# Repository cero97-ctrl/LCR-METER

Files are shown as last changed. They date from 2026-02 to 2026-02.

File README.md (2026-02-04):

# DIY LC Meter Project

This project demonstrates how to build a DIY LC Meter capable of measuring inductance (L) and capacitance (C) values using an Arduino Nano, an LM311 comparator, and a 16x2 LCD display. The LC Meter is designed to be simple, affordable, and effective for electronics enthusiasts and DIY hobbyists. It is suitable for learning about measurement principles while also being a practical tool.

## Project Highlights:

### 1 - Circuit Schematic
A detailed circuit diagram explains the working principle and interconnection of components such as the LM311 comparator, relay, calibration buttons, and measurement probes. The schematic provides a foundation for assembling the hardware.

### 2 - PCB Design
A professionally designed single-layer PCB created with KiCad ensures clean routing and minimizes interference. It includes detailed silkscreen labels for easy assembly and debugging.

### 3 - 3D Model
A realistic 3D representation of the completed PCB with components mounted, offering a clear view of the final product and component placement.

### 4 - Firmware
The Arduino Nano is programmed with custom firmware to calculate inductance and capacitance values. Measurements are displayed on a 16x2 LCD in real time.

### 5 - Calibration and Functionality
The project includes functionality for calibration, zeroing, and easy measurement. Buttons on the PCB allow users to fine-tune settings for accurate results.

---

### Features:
- Precise Measurements: Measure a wide range of inductance and capacitance values.
- User-Friendly Interface: Includes a 16x2 LCD display for real-time measurement results and intuitive feedback.
- Adjustable Calibration: Easily calibrate the device for accurate readings using the on-board calibration buttons.
- Compact and Portable: The design is compact, making it easy to use in different workspaces or carry for fieldwork.

### Instructions:
### Prepare the PCB:
Download the provided Gerber files and manufacture the PCB, or use the KiCad design to etch your own board.

### Assemble Components:
Place and solder all components as per the silkscreen labels on the PCB.

### Upload Firmware:
Use the Arduino IDE to upload the provided sketch to your Arduino Nano. Ensure all libraries are correctly installed.

### Power and Calibration:
Connect the LC Meter to a 5V power source via USB or the provided input terminals. Calibrate the device using the calibration and zero buttons for precise results.

### Start Measuring:
Connect your inductors or capacitors to the respective terminals (Lx or Cx) and observe the measurement results on the LCD.

## Watch the Build Process

You can watch the full build process of this DIY LC Meter on my YouTube channel [**Teknotrek**](https://www.youtube.com/@TeknoTrek). Click the link below to see how the circuit is assembled, soldered, and tested:

[Watch on YouTube](https://youtu.be/YbbpxDlLRkQ)

## Files Included:
- Circuit schematic
- PCB design files (KiCad)
- 3D PCB model
- Arduino firmware
- Documentation with detailed assembly and usage instructions

## Circuit Schematic

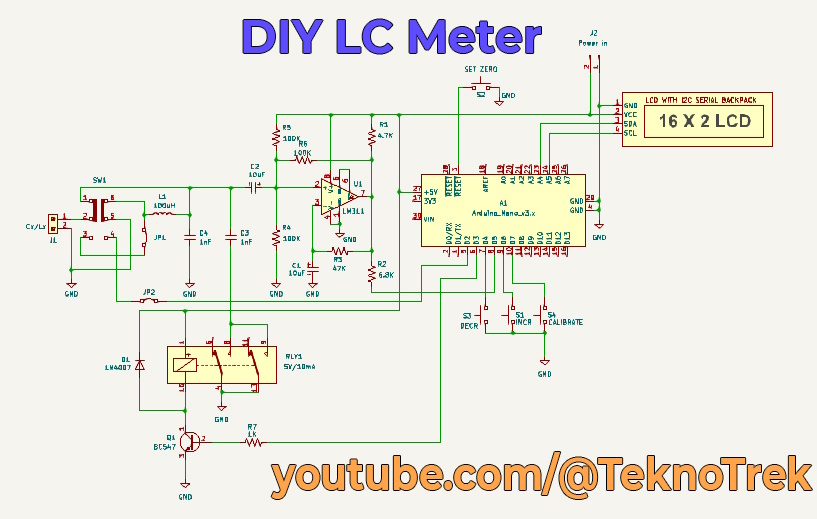
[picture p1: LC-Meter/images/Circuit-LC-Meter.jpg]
DIY LC Meter Schematic


## PCB Layout

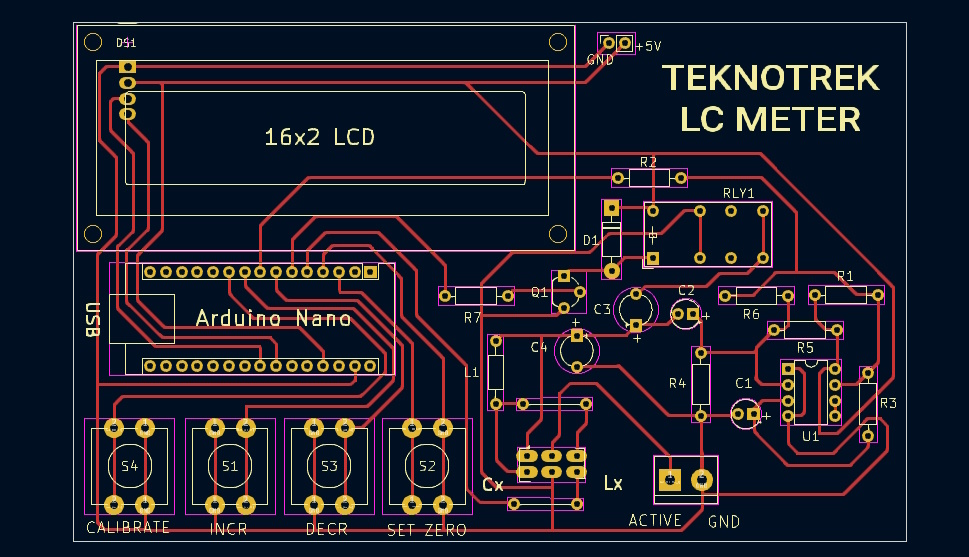
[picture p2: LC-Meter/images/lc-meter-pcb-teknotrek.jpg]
PCB Layout


## 3D Model

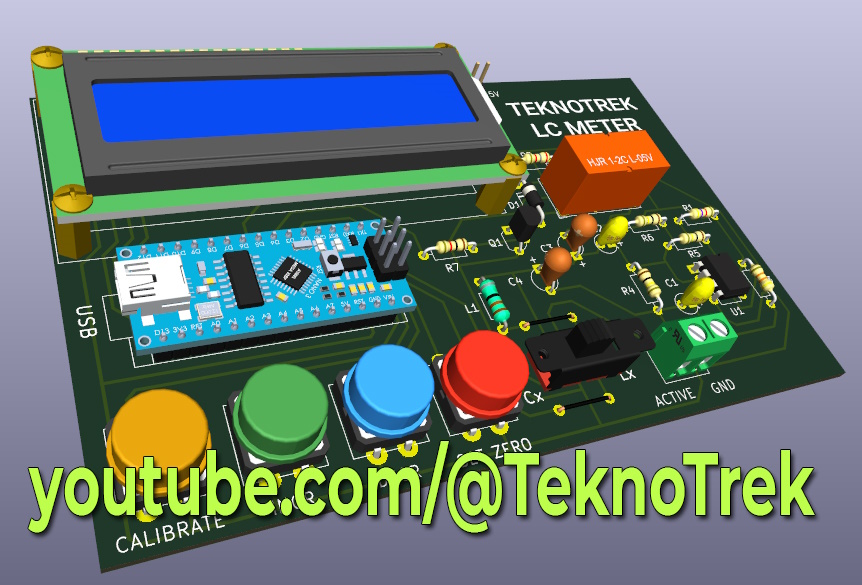
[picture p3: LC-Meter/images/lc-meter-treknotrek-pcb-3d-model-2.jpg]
3D Model


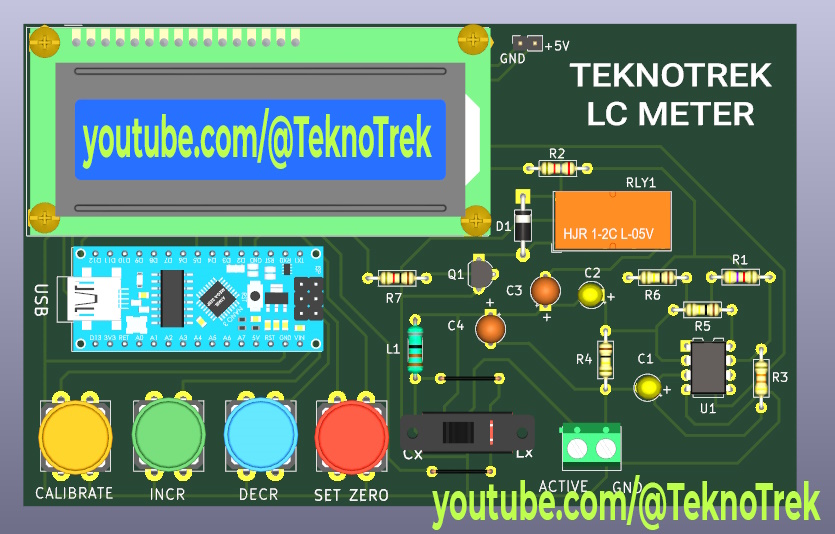
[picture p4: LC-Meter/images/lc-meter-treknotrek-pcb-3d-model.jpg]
3D Model


## GitHub Repository:
All project files, including schematics, PCB designs, 3D models, and source code, are available on GitHub.

Check out the project here: [**Teknotrek**](https://www.youtube.com/@TeknoTrek)

This project is perfect for anyone interested in electronics, DIY tools, or Arduino projects. Whether you are a beginner or an experienced maker,this LC Meter provides a hands-on learning experience and a functional tool for your electronics toolkit!

# Utilización de Arduino Mega 2560 R3.
Es totalmente posible adaptar este proyecto para utilizar un **Arduino Mega 2560 R3**. Basado en las librerías utilizadas, el soporte para el microcontrolador ATmega2560 ya está incluido, por lo que la adaptación consiste principalmente en cambios de cableado (hardware) y verificación de pines.

# Cambios de Hardware Requeridos

## 1. Entrada de Frecuencia (Librería FreqCount)
La librería `FreqCount` utiliza un temporizador de hardware específico para contar pulsos. Este pin cambia dependiendo de la placa utilizada.

    - **Arduino Nano:** Usa el **Pin 5** (Timer 1).
    - **Arduino Mega:** La librería define automáticamente el uso del **Pin 47** (Timer 5).

**Acción:** Debes conectar la señal de frecuencia (proveniente del comparador LM311) al **Pin 47** del Arduino Mega en lugar del Pin 5.

## 2. Pantalla LCD (I2C)
La comunicación I2C tiene pines dedicados diferentes en el Mega.

    - **Arduino Nano:** SDA es A4, SCL es A5.
    - **Arduino Mega:** SDA es el pin **20**, SCL es el pin **21**.

**Acción:** Conecta los pines SDA y SCL de tu pantalla LCD a los pines **20 y 21** del Arduino Mega respectivamente.

## 3. Otros Componentes (Relé y Botones)
El resto de los pines digitales (para el relé de calibración y los botones) deberían funcionar igual si utilizas los mismos números de pin definidos en el código original (por ejemplo, D2, D3, etc.), ya que el mapeo es directo en el entorno Arduino.

*Nota:* Al igual que en el Nano, la librería `FreqCount` utiliza el `TIMER2` para la ventana de tiempo. Esto significa que los pines **9 y 10** perderán su capacidad de PWM (`analogWrite`), pero pueden usarse como pines digitales normales.

# Resumen de Conexiones

lll@{}}

**Función**  |  **Arduino Nano**  |  **Arduino Mega 2560**   

Entrada Frecuencia  |  Pin 5  |  **Pin 47**   

LCD SDA  |  Pin A4  |  **Pin 20**   

LCD SCL  |  Pin A5  |  **Pin 21**   

# Notas de Software
No es necesario modificar los archivos de la librería `FreqCount`, ya que el soporte ya está incluido en el código fuente (`FreqCountTimers.h`). Asegúrate de seleccionar "Arduino Mega or Mega 2560" en tu IDE antes de subir el código.

# Consideraciones sobre el PCB
El diseño de PCB incluido en este proyecto está creado específicamente para el factor de forma del **Arduino Nano**.

    - **Factor de Forma:** El Arduino Mega 2560 es físicamente mucho más grande y tiene una disposición de pines diferente. No encajará en los zócalos diseñados para el Nano.
    - **Incompatibilidad Directa:** Debido a los cambios de pines necesarios (Pin 47 para frecuencia, 20/21 para I2C), las pistas del PCB original no conducen a los lugares correctos en el Mega.

**Recomendación:** Para usar un Arduino Mega, no se puede utilizar el archivo de fabricación de PCB actual. Se recomienda:

    - Utilizar una protoboard o placa de pruebas para realizar el cableado manualmente según la tabla de conexiones.
    - Rediseñar el PCB en KiCad si se desea una solución permanente, adaptando el diseño para que funcione como un "Shield" de Arduino Mega.

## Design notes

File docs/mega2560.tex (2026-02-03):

\documentclass{article}
\usepackage[utf8]{inputenc}
\usepackage[spanish]{babel}
\usepackage{geometry}
\usepackage{booktabs}
\usepackage{hyperref}

\geometry{a4paper, margin=1in}

\title{Adaptación del Proyecto LC Meter para Arduino Mega 2560 R3}
\author{Documentación del Proyecto}
\date{\today}

\begin{document}

\maketitle

\section{Introducción}
Es totalmente posible adaptar este proyecto para utilizar un \textbf{Arduino Mega 2560 R3}. Basado en las librerías utilizadas, el soporte para el microcontrolador ATmega2560 ya está incluido, por lo que la adaptación consiste principalmente en cambios de cableado (hardware) y verificación de pines.

\section{Cambios de Hardware Requeridos}

\subsection{1. Entrada de Frecuencia (Librería FreqCount)}
La librería \texttt{FreqCount} utiliza un temporizador de hardware específico para contar pulsos. Este pin cambia dependiendo de la placa utilizada.

\begin{itemize}
    \item \textbf{Arduino Nano:} Usa el \textbf{Pin 5} (Timer 1).
    \item \textbf{Arduino Mega:} La librería define automáticamente el uso del \textbf{Pin 47} (Timer 5).
\end{itemize}

\textbf{Acción:} Debes conectar la señal de frecuencia (proveniente del comparador LM311) al \textbf{Pin 47} del Arduino Mega en lugar del Pin 5.

\subsection{2. Pantalla LCD (I2C)}
La comunicación I2C tiene pines dedicados diferentes en el Mega.

\begin{itemize}
    \item \textbf{Arduino Nano:} SDA es A4, SCL es A5.
    \item \textbf{Arduino Mega:} SDA es el pin \textbf{20}, SCL es el pin \textbf{21}.
\end{itemize}

\textbf{Acción:} Conecta los pines SDA y SCL de tu pantalla LCD a los pines \textbf{20 y 21} del Arduino Mega respectivamente.

\subsection{3. Otros Componentes (Relé y Botones)}
El resto de los pines digitales (para el relé de calibración y los botones) deberían funcionar igual si utilizas los mismos números de pin definidos en el código original (por ejemplo, D2, D3, etc.), ya que el mapeo es directo en el entorno Arduino.

\textit{Nota:} Al igual que en el Nano, la librería \texttt{FreqCount} utiliza el \texttt{TIMER2} para la ventana de tiempo. Esto significa que los pines \textbf{9 y 10} perderán su capacidad de PWM (\texttt{analogWrite}), pero pueden usarse como pines digitales normales.

\section{Resumen de Conexiones}

\begin{table}[h]
\centering
\begin{tabular}{@{}lll@{}}
\toprule
\textbf{Función} & \textbf{Arduino Nano} & \textbf{Arduino Mega 2560} \\ \midrule
Entrada Frecuencia & Pin 5 & \textbf{Pin 47} \\
LCD SDA & Pin A4 & \textbf{Pin 20} \\
LCD SCL & Pin A5 & \textbf{Pin 21} \\ \bottomrule
\end{tabular}
\caption{Tabla comparativa de conexiones críticas.}
\label{tab:conexiones}
\end{table}

\section{Notas de Software}
No es necesario modificar los archivos de la librería \texttt{FreqCount}, ya que el soporte ya está incluido en el código fuente (\texttt{FreqCountTimers.h}). Asegúrate de seleccionar "Arduino Mega or Mega 2560" en tu IDE antes de subir el código.

\section{Consideraciones sobre el PCB}
El diseño de PCB incluido en este proyecto está creado específicamente para el factor de forma del \textbf{Arduino Nano}.

\begin{itemize}
    \item \textbf{Factor de Forma:} El Arduino Mega 2560 es físicamente mucho más grande y tiene una disposición de pines diferente. No encajará en los zócalos diseñados para el Nano.
    \item \textbf{Incompatibilidad Directa:} Debido a los cambios de pines necesarios (Pin 47 para frecuencia, 20/21 para I2C), las pistas del PCB original no conducen a los lugares correctos en el Mega.
\end{itemize}

\textbf{Recomendación:} Para usar un Arduino Mega, no se puede utilizar el archivo de fabricación de PCB actual. Se recomienda:
\begin{enumerate}
    \item Utilizar una protoboard o placa de pruebas para realizar el cableado manualmente según la tabla de conexiones.
    \item Rediseñar el PCB en KiCad si se desea una solución permanente, adaptando el diseño para que funcione como un "Shield" de Arduino Mega.
\end{enumerate}

\end{document}

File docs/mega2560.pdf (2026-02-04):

# Adaptación del Proyecto LC Meter para Arduino Mega 2560 R3

Documentación del Proyecto

4 de febrero de 2026

## 1. Introducción

Es totalmente posible adaptar este proyecto para utilizar un Arduino Mega 2560 R3. Basado en las librerías utilizadas, el soporte para el microcontrolador ATmega2560 ya está incluido, por lo que la adaptación consiste principalmente en cambios de cableado (hardware) y verificación de pines.

## 2. Cambios de Hardware Requeridos

2.1. 1. Entrada de Frecuencia (Librería FreqCount)

La librería FreqCount utiliza un temporizador de hardware específico para contar pulsos. Este pin cambia dependiendo de la placa utilizada.

Arduino Nano: Usa el Pin 5 (Timer 1).

Arduino Mega: La librería define automáticamente el uso del Pin 47 (Timer 5).

Acción: Debes conectar la señal de frecuencia (proveniente del comparador LM311) al Pin 47 del Arduino Mega en lugar del Pin 5.

2.2. 2. Pantalla LCD (I2C)

La comunicación I2C tiene pines dedicados diferentes en el Mega.

Arduino Nano: SDA es A4, SCL es A5.

Arduino Mega: SDA es el pin 20, SCL es el pin 21.

Acción: Conecta los pines SDA y SCL de tu pantalla LCD a los pines 20 y 21 del Arduino Mega respectivamente.

2.3. 3. Otros Componentes (Relé y Botones)

El resto de los pines digitales (para el relé de calibración y los botones) deberían funcionar igual si utilizas los mismos números de pin definidos en el código original (por ejemplo, D2, D3, etc.), ya que el mapeo es directo en el entorno Arduino.
Nota: Al igual que en el Nano, la librería FreqCount utiliza el TIMER2 para la ventana de tiempo. Esto significa que los pines 9 y 10 perderán su capacidad de PWM (analogWrite), pero pueden usarse como pines digitales normales.

## 3. Resumen de Conexiones

## 4. Notas de Software

No es necesario modificar los archivos de la librería FreqCount, ya que el soporte ya está incluido en el código fuente (FreqCountTimers.h). Asegúrate de seleccionar .Arduino Mega or Mega 2560.en tu IDE antes de subir el código.

1

Función | Arduino Nano | Arduino Mega 2560
Entrada Frecuencia | Pin 5 | Pin 47
LCD SDA | Pin A4 | Pin 20
LCD SCL | Pin A5 | Pin 21

Cuadro 1: Tabla comparativa de conexiones críticas.

## 5. Consideraciones sobre el PCB

El diseño de PCB incluido en este proyecto está creado específicamente para el factor de forma del Arduino Nano.

Factor de Forma: El Arduino Mega 2560 es físicamente mucho más grande y tiene una disposición de pines diferente. No encajará en los zócalos diseñados para el Nano.

Incompatibilidad Directa: Debido a los cambios de pines necesarios (Pin 47 para frecuencia, 20/21 para I2C), las pistas del PCB original no conducen a los lugares correctos en el Mega.

Recomendación: Para usar un Arduino Mega, no se puede utilizar el archivo de fabricación de PCB actual. Se recomienda:

1. Utilizar una protoboard o placa de pruebas para realizar el cableado manualmente según la tabla de conexiones.
2. Rediseñar el PCB en KiCad si se desea una solución permanente, adaptando el diseño para que funcione como un ”Shield”de Arduino Mega.

2

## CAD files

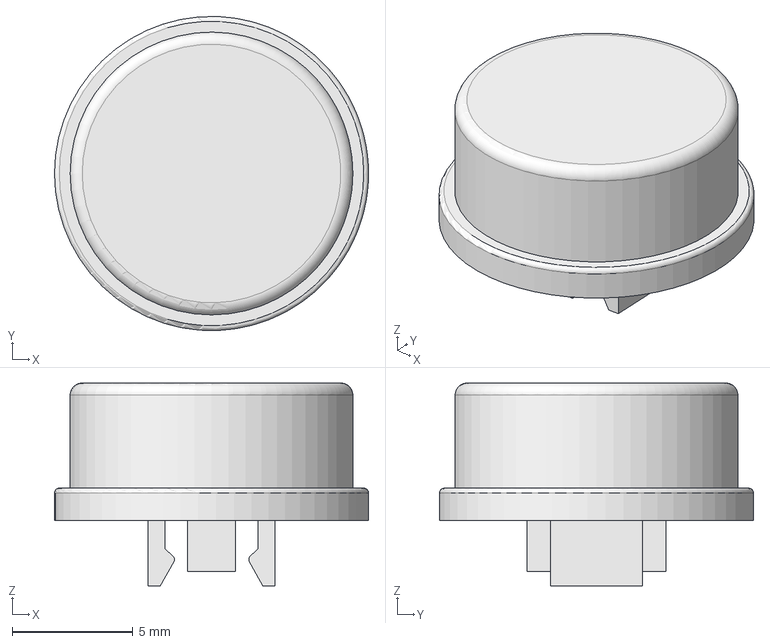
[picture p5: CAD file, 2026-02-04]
LC-Meter/materiel/KLS7_TS1204_12x12-Cap_Gray v1.step
13.0 x 13.0 x 8.40 mm

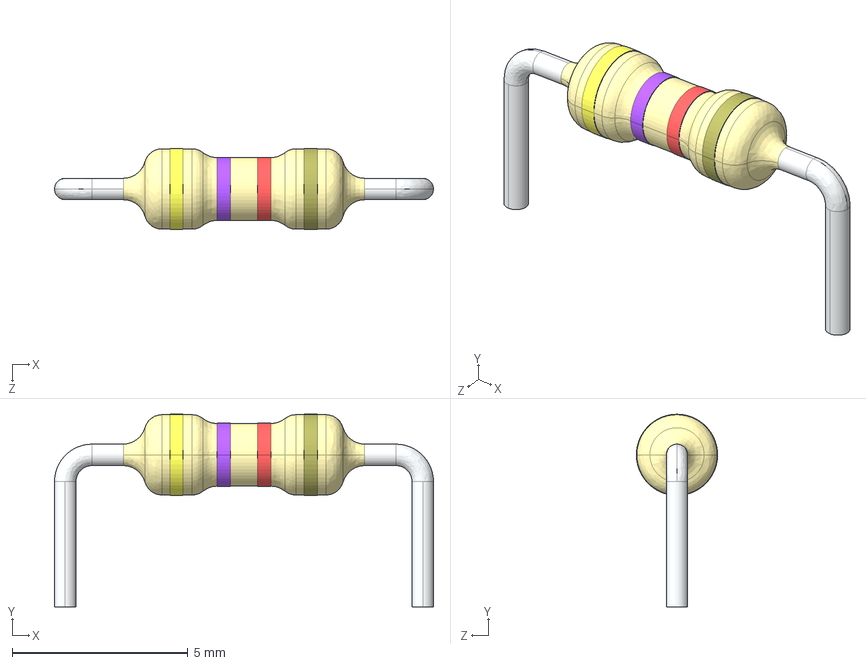
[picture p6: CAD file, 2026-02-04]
LC-Meter/materiel/4k7R 0.4.STEP
10.8 x 5.47 x 2.31 mm

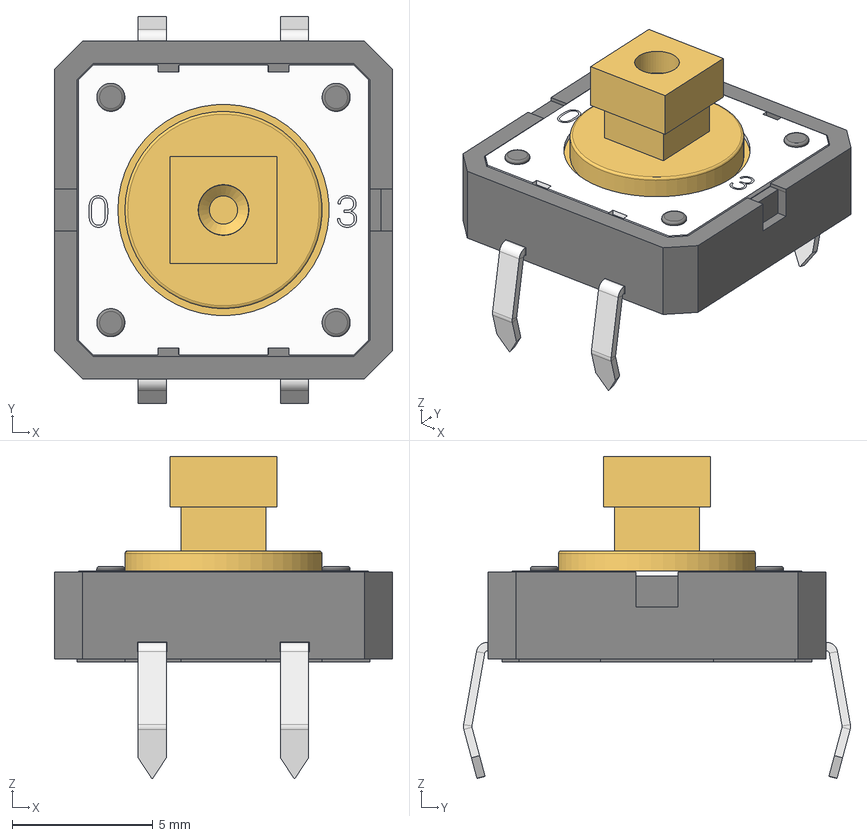
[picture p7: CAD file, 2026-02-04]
LC-Meter/materiel/KLS7_TS1204_12x12.step
12.0 x 13.7 x 11.4 mm
Head
Pin001_002
Pin003_004
Metal_plate
dig_3
dig_0
T3F
Isolator
Contact_plate

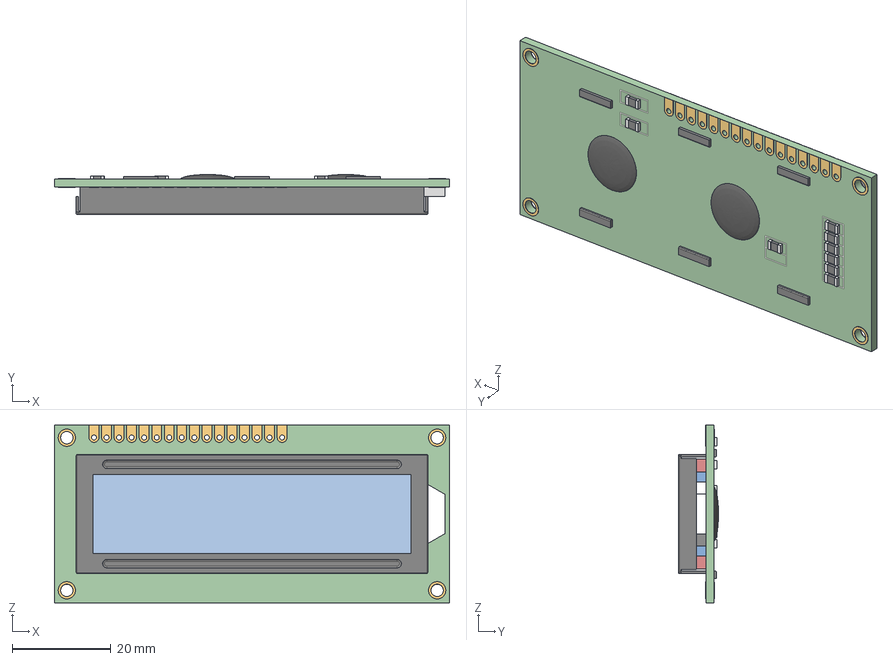
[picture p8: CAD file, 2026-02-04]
LC-Meter/materiel/1602 LCD.stp
80.0 x 8.10 x 36.0 mm
PCB
Mounting Screw Ring x 6
Mounting Screw Ring_mir x 2
Wire Connector Plating x 32
SMD_R 1206 Body x 9
SMD_R 1206 Connector x 18
LCD Conductive Band x 2
LCD Screen
LCD Glass
Round Chip x 2
LCD Frame

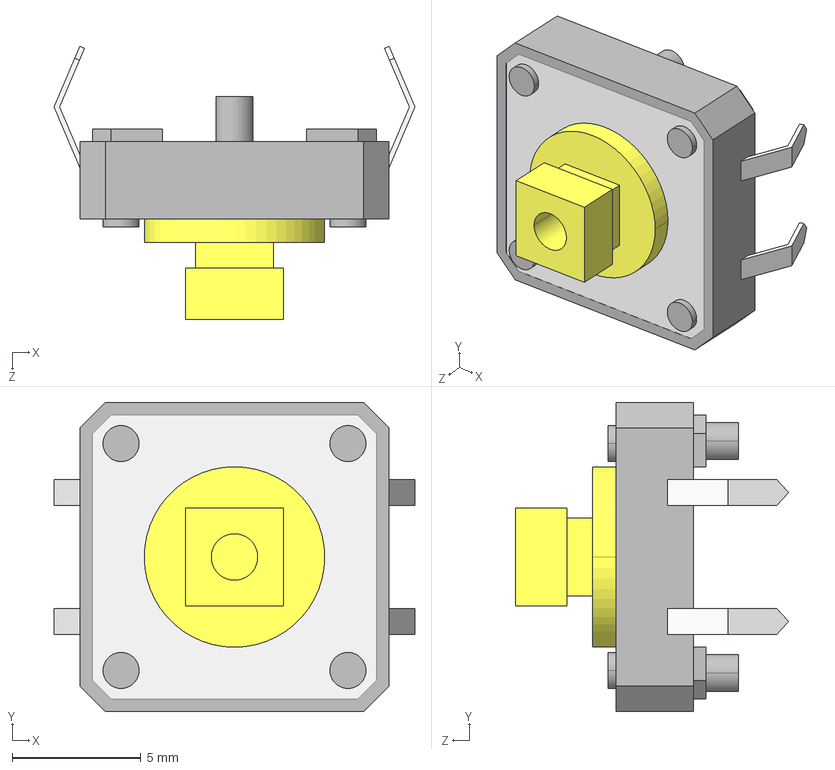
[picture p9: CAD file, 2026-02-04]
LC-Meter/materiel/OMRON B3F 12mm TACT SWITCH.STEP
14.0 x 12.0 x 10.6 mm

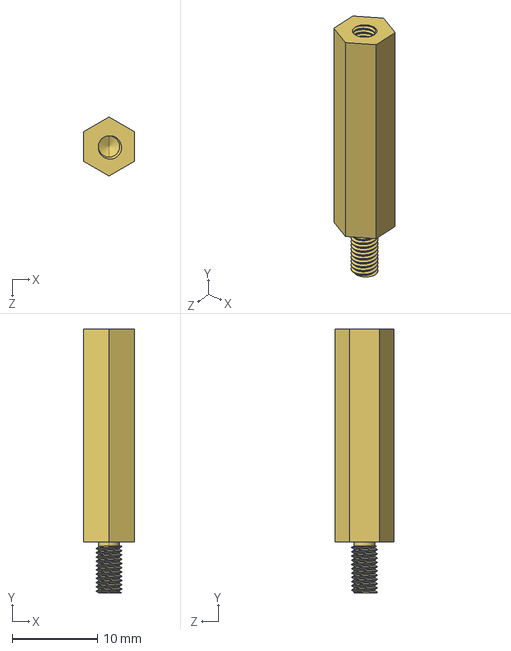
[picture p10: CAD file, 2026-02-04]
LC-Meter/materiel/M3 x 6mm A-F x 25mm Hexagon Male-Female Threaded Pillar.STEP
6.00 x 31.0 x 6.93 mm

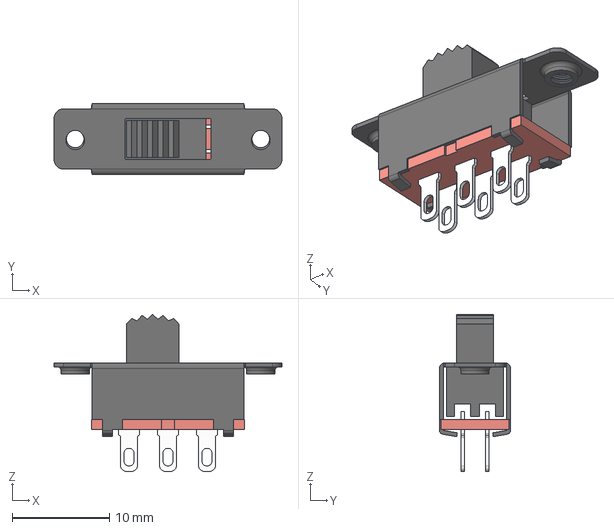
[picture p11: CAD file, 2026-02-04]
LC-Meter/materiel/Uxcell 5mm Vertical Slide Switch DPDT 6 Terminals.step
23.4 x 7.30 x 16.2 mm

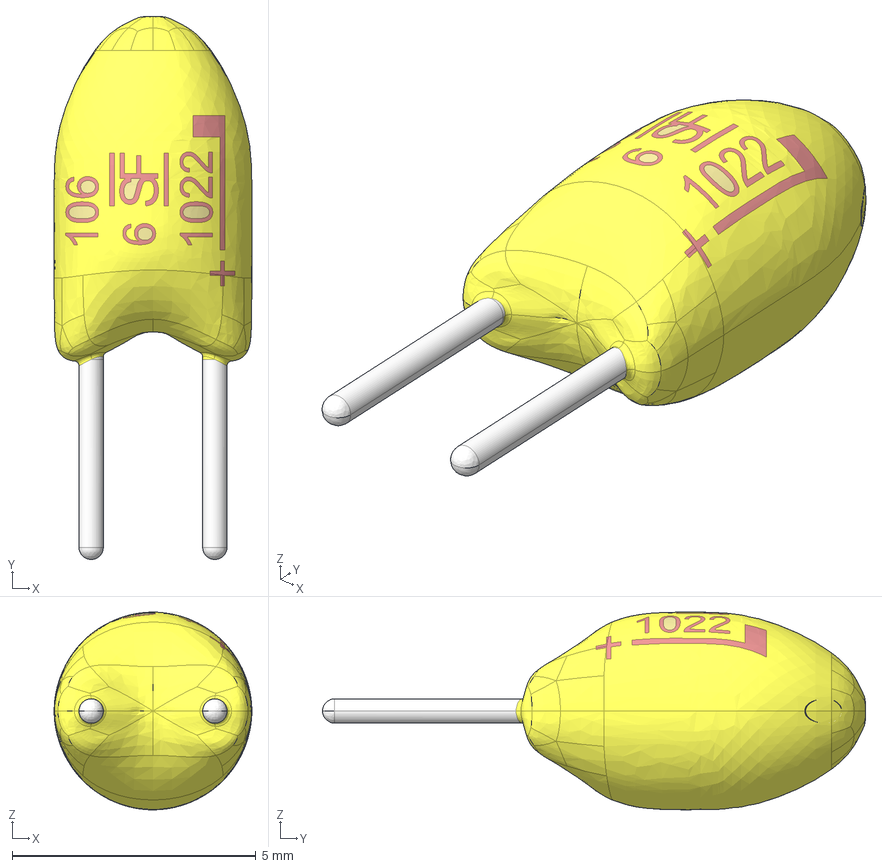
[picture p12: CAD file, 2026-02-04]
LC-Meter/materiel/Cap Tan TH –Leads L4,0mm Radial Dipped T350.stp
4.06 x 11.1 x 4.06 mm

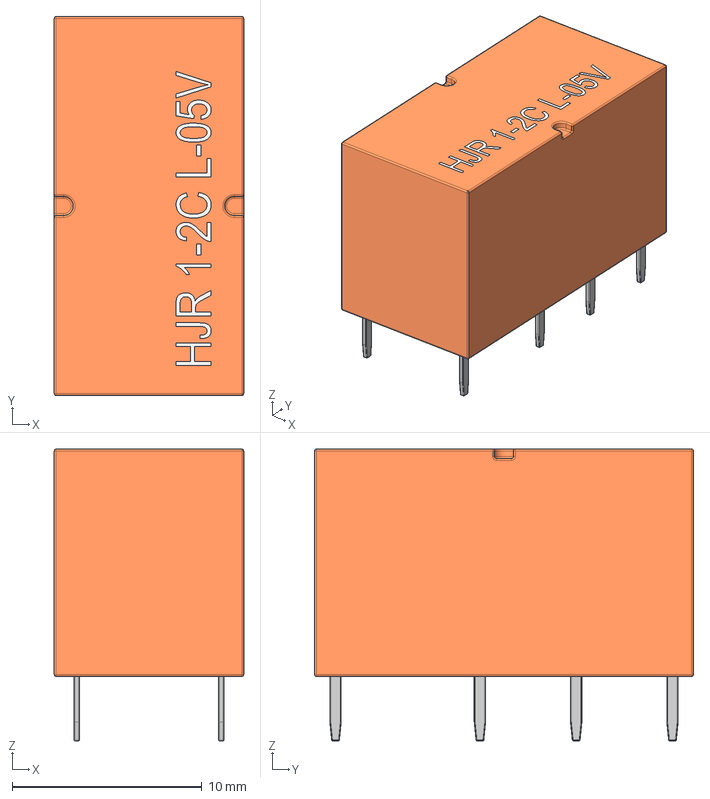
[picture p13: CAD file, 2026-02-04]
LC-Meter/materiel/HJR_Series.step
10.0 x 20.0 x 15.5 mm
ShapeString

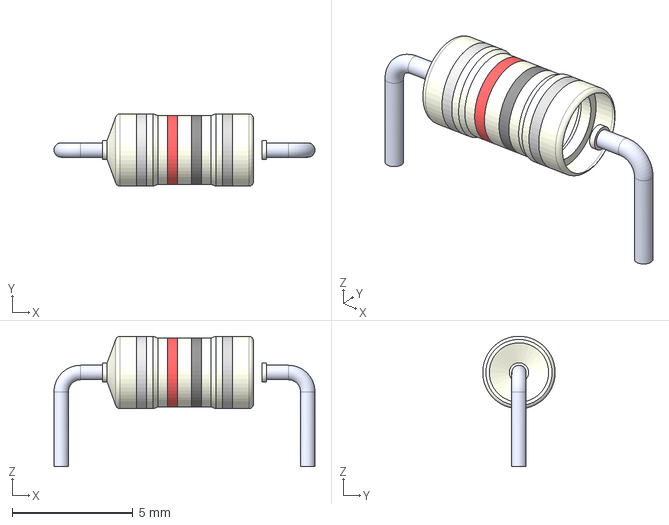
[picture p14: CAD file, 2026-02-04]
LC-Meter/materiel/INDAD1020W60L680D300 v1.step
10.8 x 3.00 x 5.40 mm

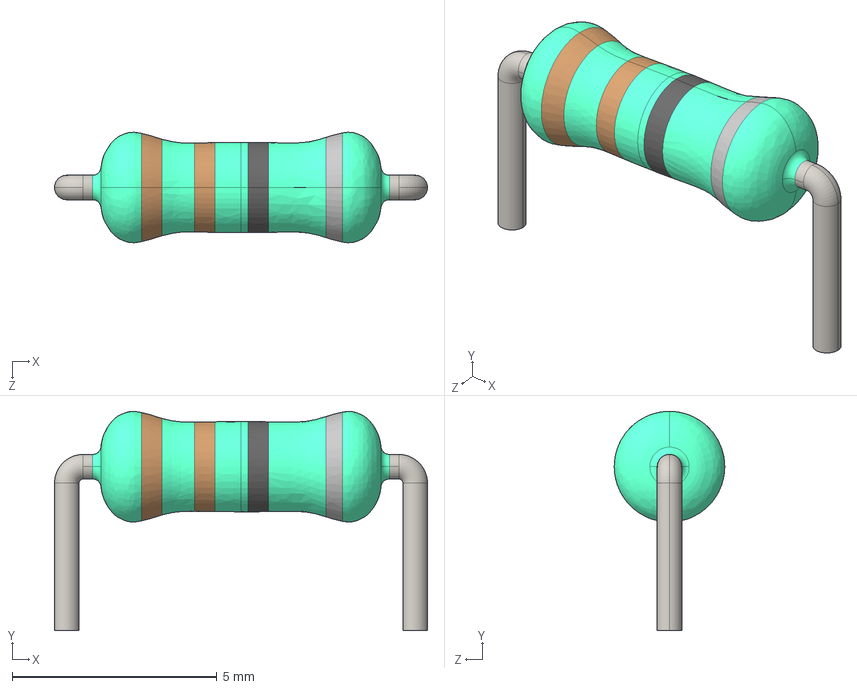
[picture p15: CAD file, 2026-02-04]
LC-Meter/materiel/inductor axial 10uH.STEP
9.10 x 5.35 x 2.70 mm

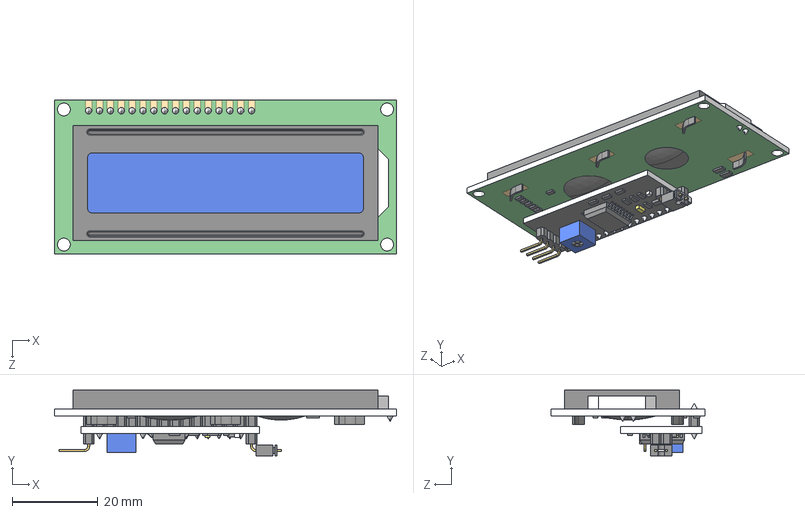
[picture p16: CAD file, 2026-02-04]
LC-Meter/materiel/LCD_I2C_1602.STEP
80.0 x 15.4 x 36.0 mm

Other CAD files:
LC-Meter/materiel/47kR 0.4.STEP
LC-Meter/materiel/KLS7_TS1204_12x12-Cap_Blue v1.step
LC-Meter/materiel/100kR 0.4.STEP
LC-Meter/materiel/6k8R 0.4.STEP
LC-Meter/materiel/KLS7_TS1204_12x12-Cap_Red v1.step
LC-Meter/materiel/Cap Tan TH –Leads L3,5mm Radial Dipped T350.stp
LC-Meter/materiel/1k 0.4.STEP
LC-Meter/materiel/2 PIN DG306-5 GREEN - PITCH 5 mm.stp
LC-Meter/materiel/Cap Tan TH –Leads L12mm Radial Dipped T350.stp
LC-Meter/materiel/DO-35 Diode Horizontal.stp
LC-Meter/materiel/Jumper.step
LC-Meter/materiel/KLS7_TS1204_12x12-Cap_Green v1.step
LC-Meter/materiel/KLS7_TS1204_12x12-Cap_Yellow v1.step
LC-Meter/materiel/M4x10 PAN POZI HEAD SERRATED SCREW BRASS.STEP
LC-Meter/materiel/Wirebridge_10.16xD0.6mm.step

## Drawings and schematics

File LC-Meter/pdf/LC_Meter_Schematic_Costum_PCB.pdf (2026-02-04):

# LC Meter Schematic

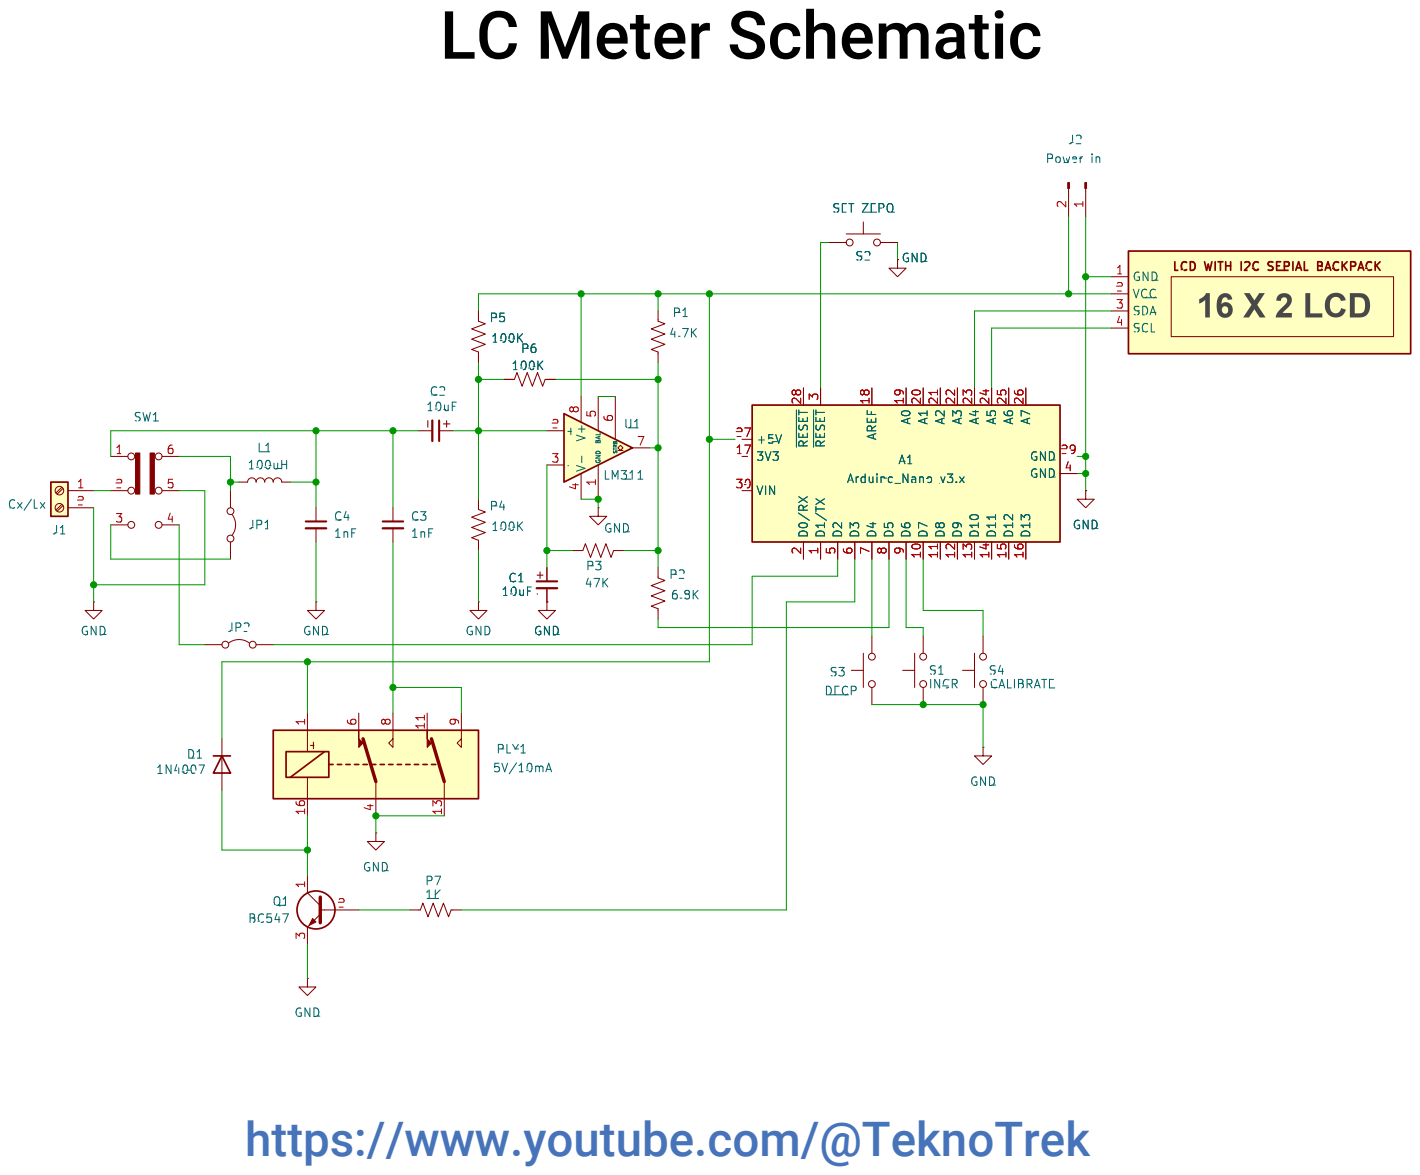
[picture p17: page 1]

LCD WITH I2C SERIAL BACKPACK GND 1
VCC 2
16 X 2 LCD

https://www.youtube.com/@TeknoTrek

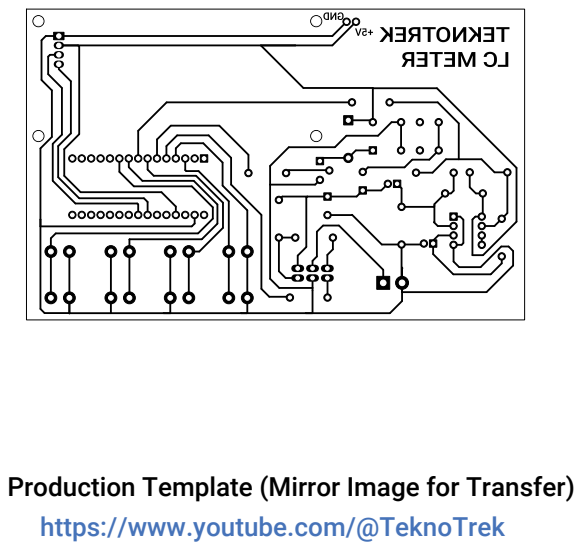
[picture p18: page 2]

Production Template (Mirror Image for Transfer)
https://www.youtube.com/@TeknoTrek

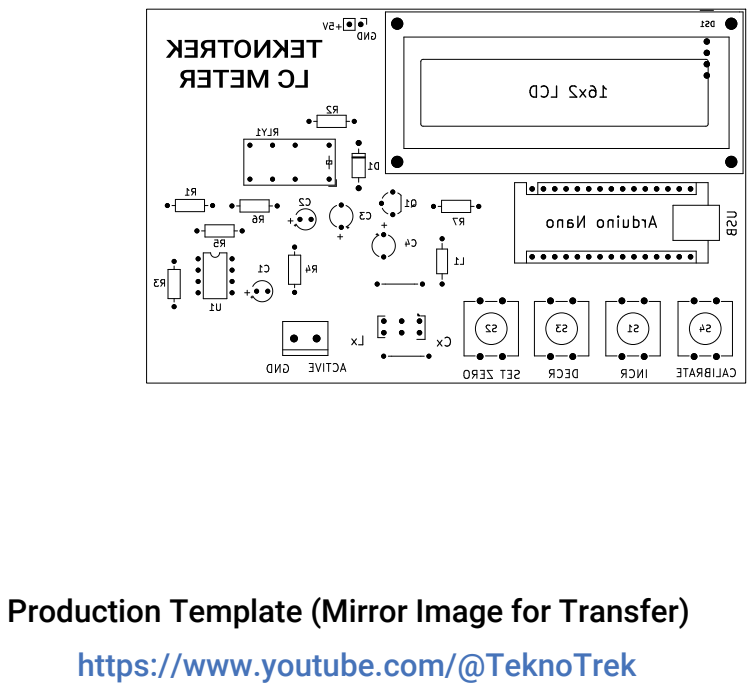
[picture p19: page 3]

Production Template (Mirror Image for Transfer) (https://www.youtube.com/@TeknoTrek)
https://www.youtube.com/@TeknoTrek

7

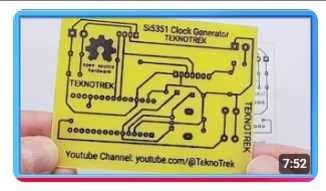
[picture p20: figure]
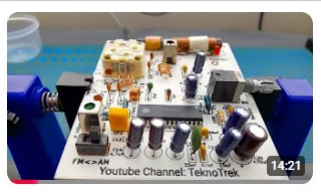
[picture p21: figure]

https://www.youtube.com/@TeknoTrek

🚀 Our Other Popular Electronics Projects
If you liked this radio, you’ll love these other projects on our channel! To access all our content, don't forget to subscribe!

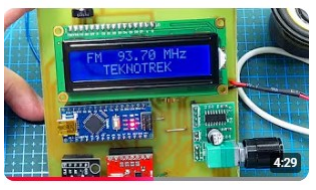
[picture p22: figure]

Home PCB Production: Easy and Fast Method! ️ | Si5351 Clock Generator (https://youtu.be/85aNuBdY58k) | How to Build a DIY FM Radio: Step-by-Step Guide with Arduino and Si4703 FM Module (https://youtu.be/up5PCYIprFo)
Watch Now (https://youtu.be/85aNuBdY58k) | Watch Now (https://youtu.be/up5PCYIprFo)

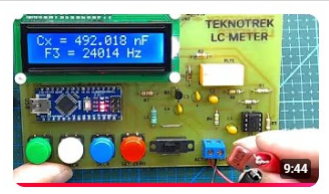
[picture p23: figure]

How to make AM / FM radio receiver at home | Powerful FM/AM Radio with CXA1019S! (https://youtu.be/TuUUNz7IGRk) | DIY Arduino-Based LC Meter - Measure Inductance and Capacitance (https://youtu.be/YbbpxDlLRkQ)
Watch Now (https://youtu.be/TuUUNz7IGRk) | Watch Now (https://youtu.be/YbbpxDlLRkQ)

To access all other videos on our channel:
Don't forget to subscribe to our channel! (https://www.youtube.com/@TeknoTrek) https://www.youtube.com/@TeknoTrek/videos

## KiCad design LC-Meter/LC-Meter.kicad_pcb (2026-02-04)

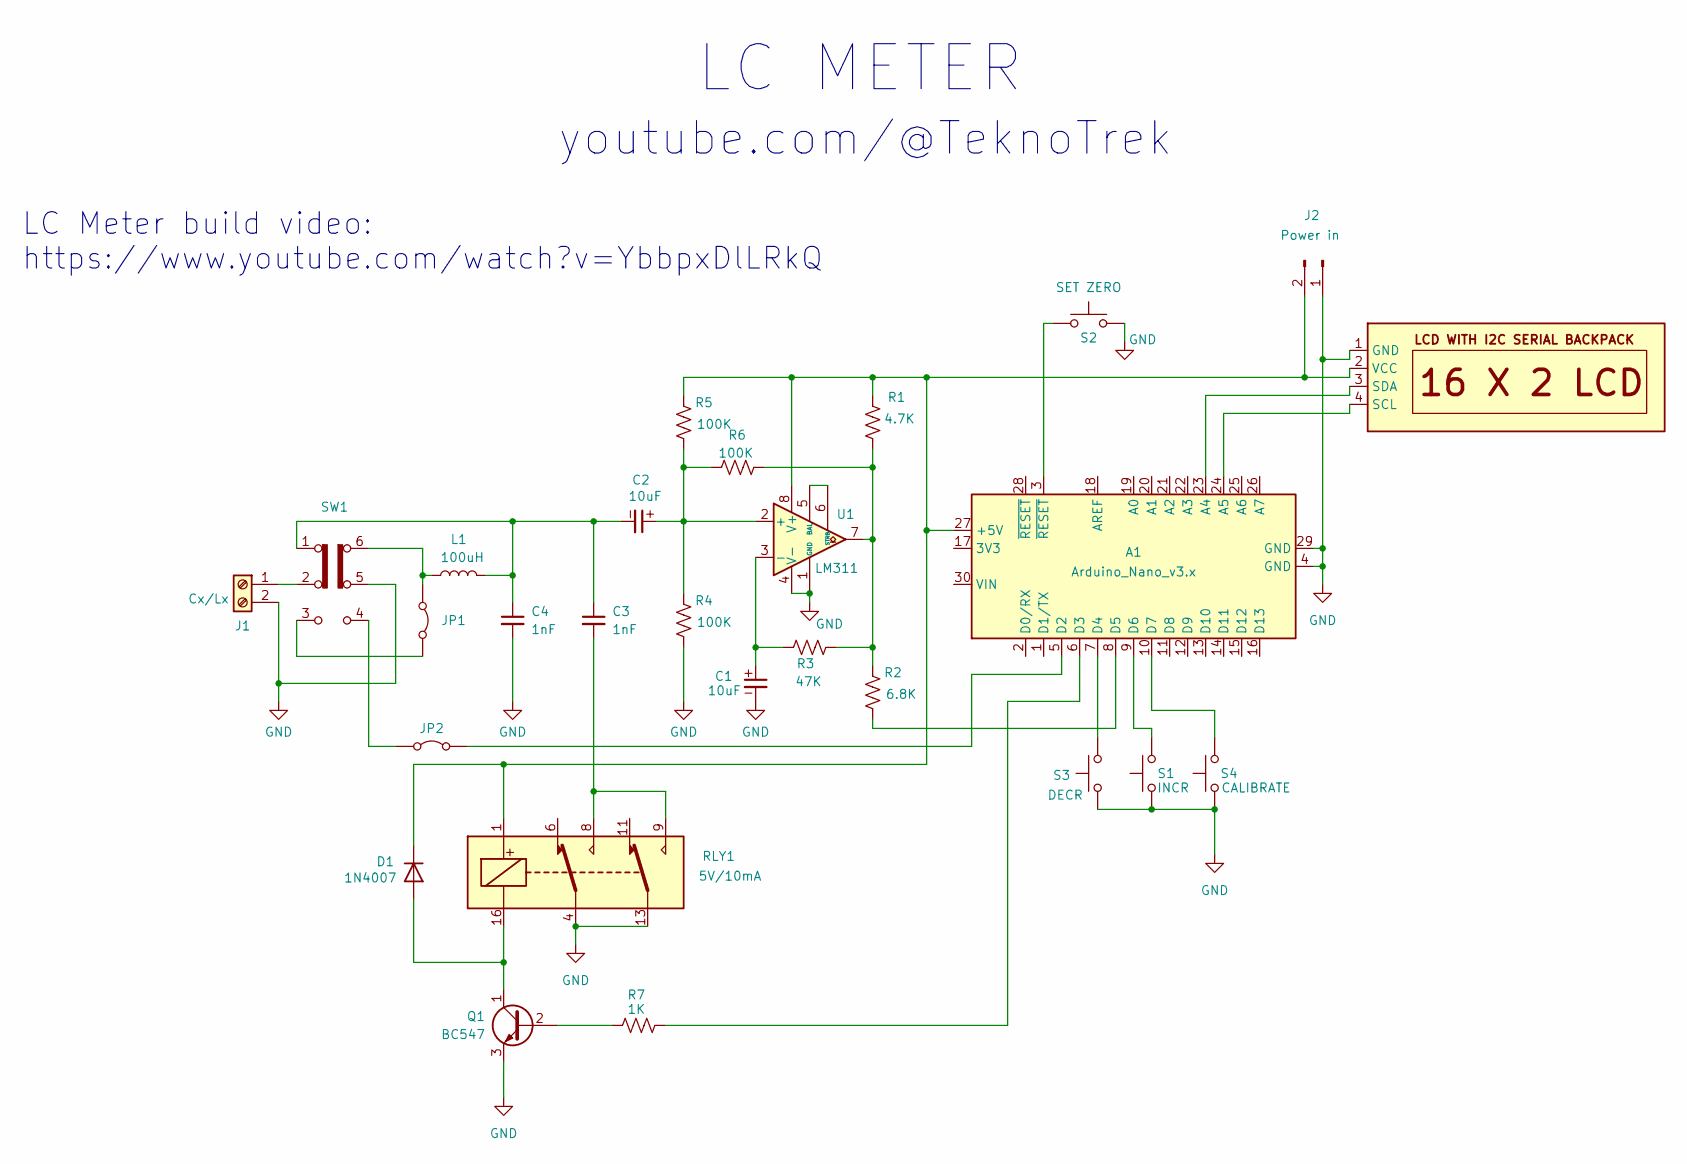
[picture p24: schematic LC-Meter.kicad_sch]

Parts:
A1: Arduino_Nano_v3.x; Arduino_Nano
C1, C2: 10uF; CP_Radial_Tantal_D4.5mm_P2.50mm
C3, C4: 1nF; CP_Radial_Tantal_D5.0mm_P5.00mm
D1: 1N4007; D_DO-41_SOD81_P10.16mm_Horizontal
DS1: WC1602A-I2C
J1: Cx/Lx; TerminalBlock_bornier-2_P5.08mm
J2: Power in; PinSocket_1x02_P2.54mm_Vertical
JP1, JP2: Jumper_2; R_Axial_DIN0207_L6.3mm_D2.5mm_P10.16mm_Horizontal
L1: 100uH; L_Axial_L5.3mm_D2.2mm_P10.16mm_Horizontal_Vishay_IM-1
Q1: BC547; TO-92_Wide
R1: 4.7K; R_Axial_DIN0207_L6.3mm_D2.5mm_P10.16mm_Horizontal
R2: 6.8K; R_Axial_DIN0207_L6.3mm_D2.5mm_P10.16mm_Horizontal
R3: 47K; R_Axial_DIN0207_L6.3mm_D2.5mm_P10.16mm_Horizontal
R4, R5, R6: 100K; R_Axial_DIN0207_L6.3mm_D2.5mm_P10.16mm_Horizontal
R7: 1K; R_Axial_DIN0207_L6.3mm_D2.5mm_P10.16mm_Horizontal
RLY1: 5V/10mA; TIANBO-HJR1-2CL-05V-footer
S1: INCR; SW_PUSH-12mm
S2: SET ZERO; SW_PUSH-12mm
S3: DECR; SW_PUSH-12mm
S4: CALIBRATE; SW_PUSH-12mm
SW1: SW_Slide_DPDT; SW_CK_
U1: LM311; DIP-8_W7.62mm

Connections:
GND: A1.4 (GND), A1.29 (GND), C1.2, C4.2, DS1.1 (GND), J1.2, J2.1, Q1.3 (E), R4.2, RLY1.4, RLY1.13, S1.1, S2.2, S3.1, S4.1, SW1.5 (B), U1.1 (GND), U1.4 (V-)
unnamed: A1.27 (+5V), D1.1 (K), DS1.2 (VCC), J2.2, R1.1, R5.1, RLY1.1, U1.8 (V+)
unnamed: A1.23 (A4), DS1.3 (SDA)
unnamed: A1.24 (A5), DS1.4 (SCL)
unnamed: A1.5 (D2), JP2.2 (B)
unnamed: A1.6 (D3), R7.2
unnamed: A1.7 (D4), S3.2
unnamed: A1.8 (D5), R2.2
unnamed: A1.9 (D6), S1.2
unnamed: A1.10 (D7), S4.2
unnamed: A1.3 (~RESET), S2.1
unnamed: C2.2, C3.1, C4.1, L1.2, SW1.1 (A)
unnamed: C3.2, RLY1.8, RLY1.9
unnamed: D1.2 (A), Q1.1 (C), RLY1.16
unnamed: J1.1, SW1.2 (B)
unnamed: JP1.1 (A), L1.1, SW1.6 (C)
unnamed: JP1.2 (B), SW1.3 (C)
unnamed: JP2.1 (A), SW1.4 (A)
unnamed: Q1.2 (B), R7.1
unnamed: R1.2, R2.1, R3.2, R6.2, U1.7
unnamed: C2.1, R4.1, R5.2, R6.1, U1.2 (+)
unnamed: C1.1, R3.1, U1.3 (-)
unnamed: U1.5 (BAL), U1.6 (STRB)

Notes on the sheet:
LC Meter build video: https://www.youtube.com/watch?v=YbbpxDlLRkQ
youtube.com/@TeknoTrek
LC METER

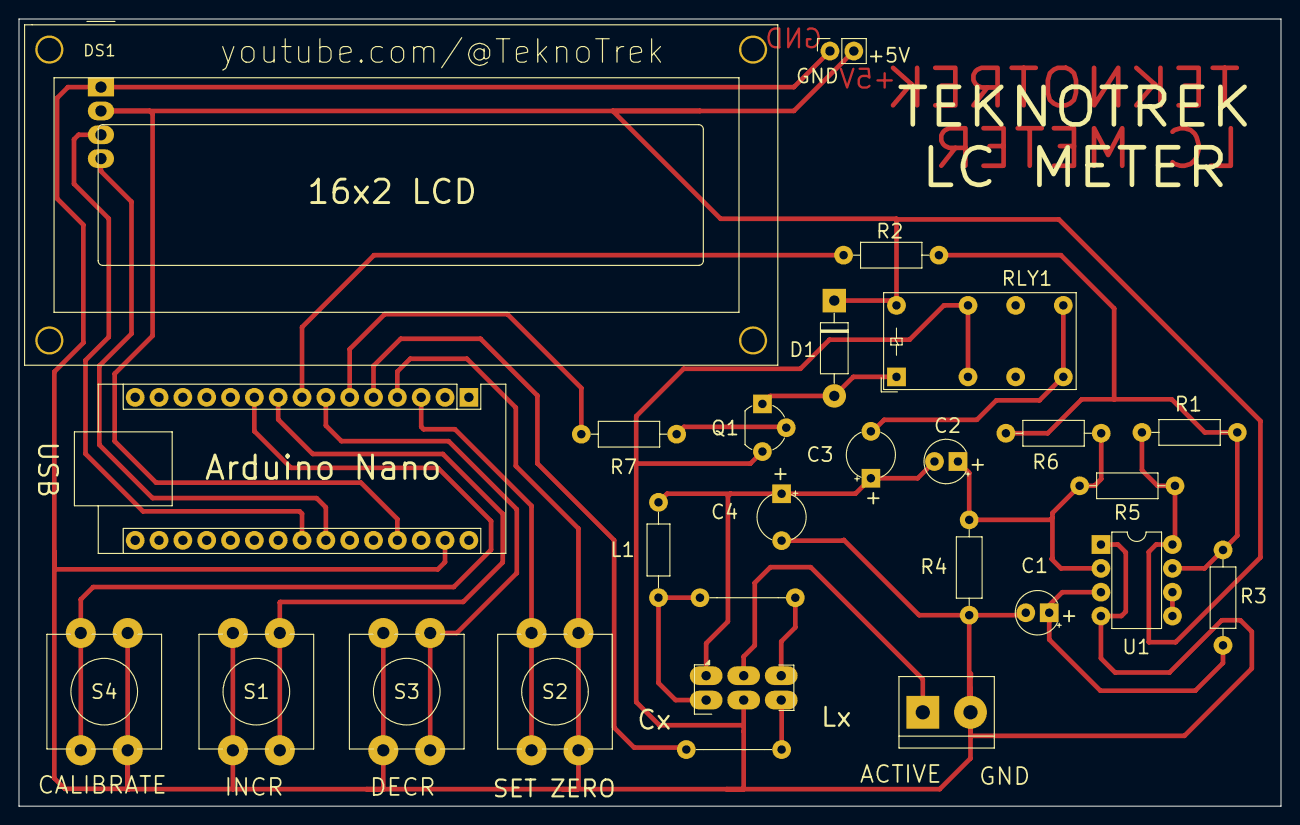
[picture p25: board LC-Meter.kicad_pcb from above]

Board: 2 copper layers, 134.5 x 83.9 mm, 27 parts (0 on the bottom side), 23 nets.

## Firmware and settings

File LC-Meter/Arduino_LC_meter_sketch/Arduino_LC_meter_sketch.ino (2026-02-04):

/* Arduino_LC_meter_sketch.ino

youtube channel : https://www.youtube.com/@TeknoTrek

 */
#include <Wire.h>
#include <LiquidCrystal_I2C.h>
LiquidCrystal_I2C lcd(0x27,16,2);   // set the LCD address to 0x27,
                                    // with 2 x 16 char lines   
#include <EEPROM.h>               // include the EEPROM library
#include <FreqCount.h>            // and the FreqCount library

// ====================================================================
// declaration of global variables
const float Pi = 3.14159;     // define Pi
const float FourPiSqrd = 39.4784;  // and Pi squared
const float uHmult = 1.0e6;   // multiplier for converting H into uH
const float mHmult = 1.0e3;   // multiplier for converting H into mH
const float pFmult = 1.0e12;  // multiplier for converting F into pF
const float nFmult = 1.0e9;   // multiplier for converting F into nF
const float uFmult = 1.0e6;   // multiplier for converting F into uF
const float C2val = 1.000e-9;   // nominal value of C2 (1nF = 1 x 10^-9F)
                              // (change to actual value if known)
const int CLbarPin = 2;   // digital IO pin 2 for C/L-bar sensing
const int RelayPin = 3;   // digital IO pin 3 for driving RLY1
const int DecrPin = 4;    // digital IO pin 4 for sensing DECR pos of S3
const int OscSigPin = 5;  // digital IO pin 5 for input of oscillator signal
const int IncrPin = 6;    // digital IO pin 6 for sensing INCR pos of S3
const int CalLkPin = 7;   // digital IO pin 7 for sensing CAL link LK1

float C1val;     // C1's calculated value after calibration (in F)
float CXval;     // calculated value for Cx (in F)
float L1val;     // calculated value for L1 after calibration (H)
float LXval;     // calculated value for Lx (in H)
float F1sqrd;    // calc value for Freq1 squared (as a float)
float F2sqrd;    // calc value for Freq2 squared (as a float)
float F3sqrd;    // calc value for Freq3 squared (as a float)
float CF = 1.0;  // calibration factor, set by nudging via S3

long Fcount;   // raw frequency count figure (from GetFrequency function)
long Freq1;    // measured Freq1 in Hz (L1 & C1 only)
long Freq2;    // measured Freq2 in Hz (L1 & (C1 + C2))
long Freq3;    // measured Freq3 in Hz (C1+Cx/L1 or C1/L1+Lx)

byte MTorNot = 0;   // flag: 0 = EEPROM addresses empty (== 255)

// ====================================================================
// setup function begins here
// ====================================================================
void setup()
{
  pinMode(CLbarPin, INPUT_PULLUP);    // make pin 2 an input with pullup
  pinMode(RelayPin, OUTPUT);          // but make pin3 an output
  digitalWrite(RelayPin, LOW);        // and initialise it to LOW
  pinMode(DecrPin, INPUT_PULLUP);     // make pin 4 an input with pullup
  pinMode(OscSigPin, INPUT);          // make pin 5 an input with no pullup
  pinMode(IncrPin, INPUT_PULLUP);     // make pin 6 an input with pullup
  pinMode(CalLkPin, INPUT_PULLUP);    // and make pin 7 an input with pullup

  lcd.init();             // initialise LCD
  lcd.backlight();
  lcd.setCursor(3,0);     // and show opening screen
  lcd.print("TEKNOTREK");
  lcd.setCursor(3,1);
  lcd.print("LC Meter");
  delay(2000);            // then pause for 2 seconds
  lcd.clear();      // then clear screen again (sets cursor to 0,0)
  
  int i = 0;          // just a counter for the loop below
  // now check to see if CF is saved in EEPROM (addresses 0 - 3)
  for (i = 0; i < 4; i++)
  {
    if (EEPROM.read(i) != 255)
    {
      MTorNot = 1;  // address not empty, so raise flag
    }
  } // end of loop checking EEPROM addresses 0-3

  if (MTorNot == 0)      // if it is empty (i.e., fresh start)
  {
    EEPROM.put(0, CF);  // save CF in EEPROM 
  }
  else
  {
    EEPROM.get(0, CF);  // otherwise retrieve saved CF from EEPROM
  }
 // now do a calibration
  {
    if(digitalRead(CLbarPin) == HIGH)
    {
      lcd.print("S1 set for C: OK"); // S1 in 'C' position, so confirm
    }
    else
    {
      lcd.print("Fit shorting bar"); // S1 in 'L' position, so signal
    }                                // need for shorting bar
    
    lcd.setCursor(0,1);               // now show "Now calibrating"
    lcd.print("Now calibrating");     // on second line (both cases)
    FindC1andL1();    // now do calibration, to find F1, F2, C1 & L1
    DispCalData();    // then display C1 & L1 (pausing for 3 secs)
    lcd.clear();
    lcd.print("Calibration done");
    lcd.setCursor(0,1);
    lcd.print("Ready to measure");
    delay(1000);
  }
} // end of setup function

 // ===================================================================
 // main loop() function begins here
 // ===================================================================
void loop()
{
  lcd.clear();                // first clear screen, then
  GetFrequency();             // go get current osc frequency
  Freq3 = Fcount;             // and copy into Freq3
  float F3 = float(Freq3);    // then convert to a float
  F3sqrd = pow(F3, 2.0);      // so it can be squared
  String Cdisp;               // declare C display string
  String Ldisp;               // declare L display string
  
  if(digitalRead(CLbarPin) == HIGH)  // if we're measuring a C
  {
    CXval = C1val * CF * (float(F1sqrd/F3sqrd) - 1.0); // work it out
    
    if(CXval < 1.0e-9)     // if CXval < 1nF
    {
      float CXpF = CXval * pFmult;  // get equiv value in pF
      Cdisp = " Cx = ";  // then assemble top line string
      Cdisp += String(CXpF, 3);
      Cdisp += " pF";
    }
    else    // value must be 1nF or more
    {
      if(CXval < 1.0e-6)    // but check if it's less than 1uF
      {
        float CXnF = CXval * nFmult;  // if so, get equiv value in nF
        Cdisp = "Cx = ";   // then assemble top line string
        Cdisp += String(CXnF, 3);
        Cdisp += " nF";
      }
      else    // value must be 1uF or more
      {
        float CXuF = CXval * uFmult;  // so get equiv value in uF
        Cdisp = "Cx = ";  // then assemble top line string
        Cdisp += String(CXuF, 3);
        Cdisp += " uF";  
      }
    }
    lcd.print(Cdisp);  // now display the cap value string
  }
  else    // CLbarPin == LOW, so we must be measuring an L
  {
    LXval = L1val * CF * (float(F1sqrd/F3sqrd) - 1.0); // work it out
    
    if(LXval < 1.0e-3)     // if LXval < 1mH
    {
      float LXuH = LXval * uHmult; // convert to uH 
      Ldisp = " Lx = "; // then assemble top line string
      Ldisp += String(LXuH, 3);
      Ldisp += " uH";
    }
    else      // value must be 1mH or more
    {
      if(LXval < 1.5e-1)
      {
        float LXmH = LXval * mHmult; // convert to mH 
        Ldisp = " Lx = "; // then assemble top line string
        Ldisp += String(LXmH, 3);
        Ldisp += " mH";
      }
      else
      {
        Ldisp = "  Over Range!";     
      }
    }
    lcd.print(Ldisp);  // show inductance value or over range msg
  }
  lcd.setCursor(1,1);     // then show F3 on second line
  String F3disp = "F3 = ";
  F3disp += String(Freq3);
  F3disp += " Hz";
  lcd.print(F3disp);
  
  // next section is for calibration nudging, only when LK1 is fitted 
  if(digitalRead(CalLkPin) == LOW)  // if LK1 is fitted, check S3
  {               // because it looks like some nudging is needed
    if(digitalRead(IncrPin) == LOW) // if it's increment,
    {
      CF = CF * 1.005;   // nudge up CF by 0.5%
      EEPROM.update(0, CF); // then resave new CF in EEPROM 
    }
    if(digitalRead(DecrPin) == LOW) // or if it's decrement,
    {
      CF = CF * 0.995;  // nudge CF down by 0.5%
      EEPROM.update(0, CF); // then resave new CF in EEPROM 
    }
    // note that nudging only occurs when CalLkPin is LOW (i.e., LK1
    // fitted) AND either IncrPin or DecrPin is taken LOW by S3.
    // Otherwise nothing occurs!
  }
  delay(1500);
}      // end of main loop

// =====================================================================
// FindC1andL1() fn: for initial calibration
// =====================================================================
void FindC1andL1()
{
  digitalWrite(RelayPin, LOW);  // make sure RLY1 is off (for C1 only)
  GetFrequency();               // go get Fosc
  Freq1 = Fcount;               // and copy into Freq1
  digitalWrite(RelayPin, HIGH); // now turn on relay to add C2
  delay(1000);                  // pause to allow osc to settle
  GetFrequency();               // then go get Fosc again
  Freq2 = Fcount;               // and copy into Freq2
  digitalWrite(RelayPin, LOW);  // then turn off relay again
  
  // now find the values of C1 and L1, knowing C2, Freq1 & Freq2
  float F1 = float(Freq1);      // first convert F1 and F2 to floats
  float F2 = float(Freq2);
  F1sqrd = pow(F1, 2.0);       // then find their squares
  F2sqrd = pow(F2, 2.0);
  float F1sqlessF2sq = (F1sqrd - F2sqrd); // & their difference
  C1val = C2val * float(F2sqrd / F1sqlessF2sq);    // then work out C1
  L1val = 1.0/(FourPiSqrd * float(F1sqrd) * C1val);  // and L1
  return; 
}  // end of FindC1andL1 function

// =====================================================================
// GetFrequency() fn: to measure IC1's current oscillating frequency
// =====================================================================
void GetFrequency()
  {
  FreqCount.begin(1000);   // start counter, with a gating time of 1 sec  
  while (!FreqCount.available())  // loop until Fcount is available
    {
    }
  Fcount = FreqCount.read();   // when it's available, read into Fcount
  FreqCount.end();        // and close off counter before leaving
  return;
  } // end of GetFrequency function

// =====================================================================
// DispCalData() fn: to display calibration data (C1 and L1)
// =====================================================================
void DispCalData()
{
  float L1uH = L1val * uHmult; // find uH equivalent of L1val
  float C1pF = C1val * pFmult; // and the pF equivalent of C1val
  
  lcd.clear();      // first clear screen again (sets cursor to 0,0)
  String C1disp = "C1= ";  // then assemble C1 display string
  C1disp += String(C1pF, 2);
  C1disp += " pF";
  lcd.print(C1disp); // and display on top line
  lcd.setCursor(0,1);     // then move down to second line
  String L1disp = "L1= ";
  L1disp += String(L1uH, 2);
  L1disp += "uH";
  lcd.print(L1disp);  // and display on second line
  delay(3000);        // pause for 3 seconds to allow digesting
  return;         // before returning
} // end of DispCalData function

// =====================================================================
//    end of code

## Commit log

2026-02-03 WIP: guardar cambios antes de pull
2026-02-04 Arreglar: Integrar archivos de LC-Meter eliminando repositorio anidado
    [100kR 0.4.STEP, 1602 LCD.stp, 1k 0.4.STEP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]
